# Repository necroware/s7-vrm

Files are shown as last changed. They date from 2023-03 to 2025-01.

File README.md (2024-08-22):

# Necroware's S7-VRM

This project is a Voltage Regulator Module for the Socket 7 mainboards as
defined by Intel in it's Pentium® Processor Flexible Motherboard Design
Guidelines. You can upgrade VRM capable Socket 7 mainboards with this module to
be able to use dual-voltage CPUs like Intel Pentium MMX, AMD K6, AMD K6-2 etc.

*Disclaimer: this VRM can damage your mainboard, CPU or both. Please use at your
own risk.*

__WARNING:__ *inserting the module the wrong way around would put +12V on all
critical lanes. It would destroy the mainboard, the CPU, the memory and all
expansion cards. This can't happen on mainboards with VRM socket, because there
it is not possible to insert it in reverse. On free standing VRM pin header, it
is probably a good idea to cut +12V pin 5 and the unused pin 22 to use them as
a key.*

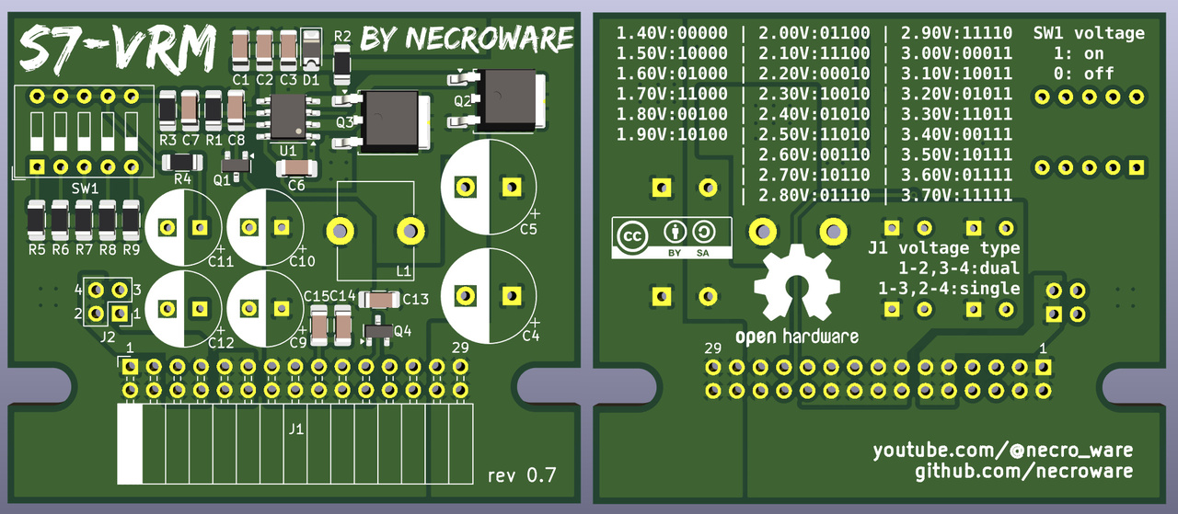
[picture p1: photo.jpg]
S7-VRM


Youtube Videos:
- Part 1: https://youtu.be/CMiGVQbMC5U
- Part 2: https://youtu.be/J0NLGfocviU
- Part 3: https://youtu.be/kBPp9EAIC8I
- Part 4: https://youtu.be/XV0b5Tvf5gY

## CPU Voltage Type Selection (J1)

There are two kind of socket 7 CPUs, single-voltage and dual-voltage CPUs.
Dual-voltage CPUs are designed to use different voltages for the internal core
and for the I/O. The I/O voltage is specified at 3.3-3.5V, but the core voltage
can be much lower. For the very power efficient AMD K6-III+EE the core voltage
is just 1.6V. 

From revision 0.6 and higher the S7-VRM supports both types of CPUs, where
for the single-voltage CPUs the voltage is completely generated on the module
and for dual-voltage CPUs the I/O voltage is generated by a linear voltage
regulator on the mainboard, where core voltage is generated on the VRM module.

To make this work you have to set the jumper J1 accordingly. Please read which
kind of CPU you have before using this module.

Voltage Type | J1 Pos.  | CPU examples
-------------|----------|---------------------------------------------------
Single       | 1-3, 2-4 | Intel Pentium, AMD K5, Winchip C6, Cyrix M1
Dual         | 1-2, 3-4 | Intel Pentium MMX, AMD K6, Cyrix M1L/MII

## CPU Voltage Selection (SW1)

__WARNING__: Single voltage CPUs are designed to run at 3.3-3.5V everything
below that value could potentially make your system unstable. Everything above
that can damage your mainboard or CPU or both. Dual-voltage CPUs usually need
core voltages far below 3.0V, AMD K6-2 for example expects only 2.2V core
voltage and everything above that can potentially damage the CPU. Always pay
attention to the CPU type you use and apply voltages out of spec only if you
really know what you are doing.

__WARNING__: different revisions can have different voltage settings, please
always pay attention and look into the proper documentation for the revision
you have.

Various voltages can be set using the SW1 switch on the module (0=off, 1=on):

Voltage | Switches | CPU Examples
--------|----------|-------------------------------------------
  1.4V  |  00000   | *Probably too low for any S7 CPU*
  1.5V  |  10000   |
  1.6V  |  01000   | AMD K6-2E+ / K6-3E+ / Mobile K6-2
  1.7V  |  11000   |
  1.8V  |  00100   |
  1.9V  |  10100   |
  2.0V  |  01100   | Cyrix MII (0,18µm version)
  2.1V  |  11100   | 
  2.2V  |  00010   | AMD Mobile K6 / K6-2(+) / K6-3(+)
  2.3V  |  10010   | 
  2.4V  |  01010   | AMD K6-2
  2.5V  |  11010   |
  2.6V  |  00110   | 
  2.7V  |  10110   |
  2.8V  |  01110   | Intel Pentium MMX, IBM 6x86L, Rise MP6 
  2.9V  |  11110   | AMD K6, IBM 6x86MX
  3.0V  |  00011   | 
  3.1V  |  10011   | 
  3.2V  |  01011   | AMD K6@233
  3.3V  |  11011   | Pentium 66-200 (Single Voltage)
  3.4V  |  00111   | 
  3.5V  |  10111   | AMD K5, Winchip C6
  3.6V  |  01111   | 
  3.7V  |  11111   | *Danger: probably to high for any S7 CPU*

## Important remarks

The transistor Q1 with integrated pull-up resistor is optional. It is used for 
enable/disable signal and is unused on most mainbards.

The PCB is made for a through hole inductor, but if you have only SMD it is also
possible to solder that instead. Keep in mind that the inductor has to stand
the required current. Also slightly different inductors are allowed, everything
between 2µH and 4,7µH should work as well. With the higher inductance you get
less current ripple, also voltage ripple can look better, but the maximum
possible current will decrease. Playing with different inductors will also
influence the compensation network.

Capacitors C7 and C8 are used in so called compensation network and are
responsible for DC-DC converter activation and stability. Those parts are very
delicate and dependent on the ESR and values of the output capacitors C9-C12,
and the inductor L1. If your regulator shows stability issues or not starting
at all, try to remove the capacitor C8. If you change any other parts C7, C8 and
R1 have to be adapted accordingly.

## Bill of materials

Part        | Count | LCSC#    | Comment
------------|-------|----------|--------------------------------------------
C1, C15     | 2     | C13585   | 10u capacitor SMD 1206              
C2, C14     | 2     | C51205   | 4.7u capacitor SMD 1206              
C3, C6, C13 | 3     | C696845  | 0.1u capacitor SMD 1206
C4, C5      | 2     | C407963  | 2200u capacitor TH Radial D10.0mm, P5.00mm
C7          | 1     | C107186  | 242n capacitor SMD 1206
C8          | 1     | C577176  | 39p capacitor SMD 1206
C9-C12      | 4     | C407858  | 1000u capacitor TH Radial D8.0mm, P3.5mm
D1          | 1     | C109000  | Switching diode
J1          | 1     | C2897435 | Connector angled 02x15 pins 2.54mm 
J2          | 1     | N/A      | 2x2 jumper
L1          | 1     | N/A      | 3.3µH inductor
Q1          | 1     | C13871   | NPN-BEC biased transistor 
Q2, Q3      | 2     | C496603  | N-MOSFET GDS at least 15A
Q4          | 1     | C454937  | PNP-BEC biased transistor 
R1, R2, R6  | 3     | C136874  | 15K resistor SMD 1206
R3, R8, R9  | 3     | C706412  | 3,75K resistor SMD 1206
R4          | 1     | C870818  | 5K resistor SMD 1206
R5          | 1     | C137314  | 30K resistor SMD 1206
R7          | 1     | C137115  | 7,5K resistor SMD 1206
SW1         | 1     | C5299506 | DIP-10 Switch THT 5 buttons 2.54mm
U1          | 1     | C382017  | ISL6545 DC-DC Controller

The inductor doesn't need to be very exact, anything between 2.5µH and 4.7µH
should work, but the sweet point is at around 3.3µH. The inductor can be self
made by using a T50 ferrite toroid. For example T50-26 with permeability 75µ
wrapped in 10 loops of 1.3 mm coper.

## Tested mainboards

This module should run with all mainboards, which provide the VRM module header
as specified in Intel Pentium Mainboard Design Guidelines. Most of such boards
were based on Intel Triton (i430FX) and VIA Apolo Master (MV series) chipsets,
but there were also quite a lot of later boards with newer chipsets (f.e.
i430VX), which supported such an external VRM as well.

Most of the mainboards which were equipped with a VRM option, were produced
before Intel Pentium MMX, AMD K6 and other dual-voltage CPUs were officially
available. However those CPUs have changed the multiplier selection behavior of
CPU pins BF0/1. Not only a new pin was introduced for higher multipliers, but
also pin BF0 was not pulled up internally anymore as it has been done on
single-voltage CPUs before. This ended up in wrong multiplier detection on newer
CPUs like Pentium MMX 200, which would be suddenly detected as 166MHz one. This
can be fixed by adding a 10k pull-up resistor to the CPU between pin BF0 I/O
VCC. In the following table of tested mainboards you can find a column R+BF0
which tells if such a pull-up resistor had to be added to properly support the
multiplier settings.

Faster Super Socket 7 CPUs, like AMD K6-2 and newer added another multiplier
selection pin BF2, which is not supported on those old mainboards at all. It
can be added using another mod, but is actually not necessary. If the CPU
multiplier is set to 2x, those newer CPUs would interpret it as 6x and for
66MHz FSB go directly to 400MHz. However to be able to detect the CPU properly
you would need to mod the BIOS. This is however optional, the system should
work also with outdated BIOS. In such a case the CPU just would not be reported
properly. 

With that in mind this VRM was tested using various CPUs and voltages on
following mainboards:

Manufacturer | Model           | Chipset | R+BF0 | BIOS Mod | VRM Compatible
-------------|-----------------|---------|-------|----------|-------------------
Asus         | P/I-P55TP4XE(G) | i430FX  | Yes   | Yes      | Yes
Gigabyte     | GA-586-ATE/P    | i430FX  | Yes   | Yes      | Yes

## License

This work is licensed under the Creative Commons Attribution-ShareAlike 4.0
International License.

## Links
* [Intel Pentium Mainboard Design Guidelines](http://netwinder.osuosl.org/pub/misc/docs/i386/24318702.pdf)

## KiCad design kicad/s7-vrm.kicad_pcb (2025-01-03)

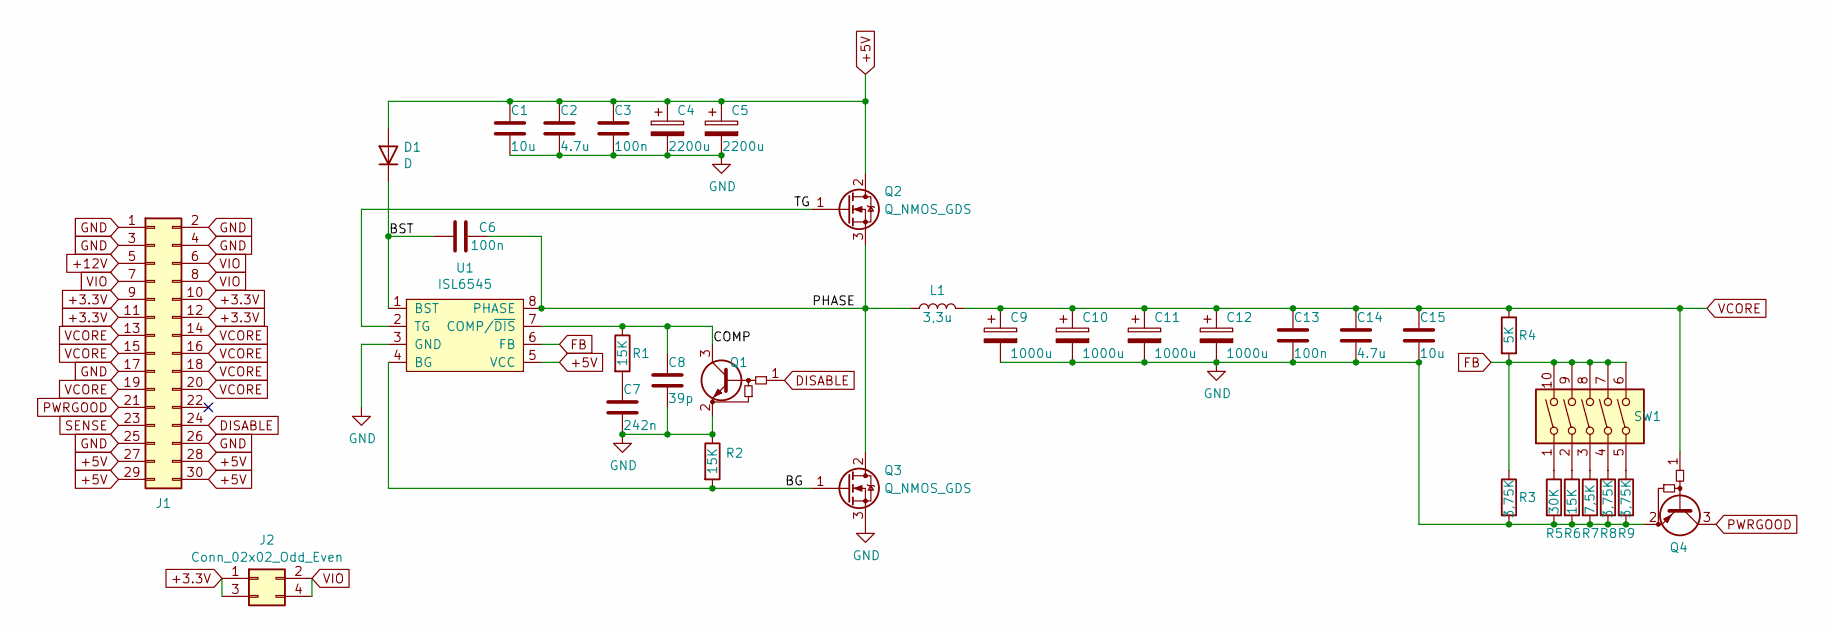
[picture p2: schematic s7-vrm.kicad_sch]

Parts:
C1, C15: 10u; C_1206_3216Metric_Pad1.33x1.80mm_HandSolder; LCSC C13585
C2, C14: 4.7u; C_1206_3216Metric_Pad1.33x1.80mm_HandSolder; LCSC C51205
C3, C6, C13: 100n; C_1206_3216Metric_Pad1.33x1.80mm_HandSolder; LCSC C696845
C4, C5: 2200u; CP_Radial_D10.0mm_P5.00mm; LCSC C407963
C7: 242n; C_1206_3216Metric_Pad1.33x1.80mm_HandSolder; LCSC C107186
C8: 39p; C_1206_3216Metric_Pad1.33x1.80mm_HandSolder; LCSC C577176
C9, C10, C11, C12: 1000u; CP_Radial_D8.0mm_P3.50mm; LCSC C407858
D1: D; D_1206_3216Metric_Pad1.42x1.75mm_HandSolder; LCSC C109000
J1: Conn_02x15_Row_Letter_First; PinSocket_2x15_P2.54mm_Horizontal; LCSC C2897435
J2: Conn_02x02_Odd_Even; PinHeader_2x02_P2.54mm_Vertical
L1: 3,3u; L_Toroid_Vertical_L16.0mm_W8.0mm_P7.62mm
Q1: Q_NPN_BEC_BRT; SOT-23; LCSC C13871
Q2, Q3: Q_NMOS_GDS; TO-252-2; LCSC C496603
Q4: Q_PNP_BEC_BRT; SOT-23; LCSC C454937
R1, R2, R6: 15K; R_1206_3216Metric_Pad1.30x1.75mm_HandSolder; LCSC C136874
R3, R8, R9: 3,75K; R_1206_3216Metric_Pad1.30x1.75mm_HandSolder; LCSC C706412
R4: 5K; R_1206_3216Metric_Pad1.30x1.75mm_HandSolder; LCSC C870818
R5: 30K; R_1206_3216Metric_Pad1.30x1.75mm_HandSolder; LCSC C137314
R7: 7,5K; R_1206_3216Metric_Pad1.30x1.75mm_HandSolder; LCSC C137115
SW1: SW_DIP_x05; SW_DIP_SPSTx05_Slide_9.78x14.88mm_W7.62mm_P2.54mm; LCSC C5299506
U1: ISL6545; SOIC-8_3.9x4.9mm_P1.27mm; LCSC C382017

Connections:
+3.3V: J1.9, J1.10, J1.11, J1.12, J2.1, J2.3
+5V: C1.1, C2.1, C3.1, C4.1, C5.1, D1.2 (A), J1.27, J1.28, J1.29, J1.30, Q2.2 (D), U1.5 (VCC)
+12V: J1.5
/BG: Q3.1 (G), R2.2, U1.4 (BG)
/BST: C6.1, D1.1 (K), U1.1 (BST)
/COMP: C8.1, Q1.3 (C), R1.1, U1.7 (COMP/~DIS)
/PHASE: C6.2, L1.1, Q2.3 (S), Q3.2 (D), U1.8 (PHASE)
/TG: Q2.1 (G), U1.2 (TG)
DISABLE: J1.24, Q1.1 (B)
FB: R3.1, R4.2, SW1.6, SW1.7, SW1.8, SW1.9, SW1.10, U1.6 (FB)
GND: C1.2, C2.2, C3.2, C4.2, C5.2, C7.2, C8.2, C9.2, C10.2, C11.2, C12.2, C13.2, C14.2, C15.2, J1.1, J1.2, J1.3, J1.4, J1.17, J1.25, J1.26, Q1.2 (E), Q3.3 (S), Q4.2 (E), R2.1, R3.2, R5.2, R6.2, R7.2, R8.2, R9.2, U1.3 (GND)
unnamed: C7.1, R1.2
unnamed: R5.1, SW1.1
unnamed: R6.1, SW1.2
unnamed: R7.1, SW1.3
unnamed: R8.1, SW1.4
unnamed: R9.1, SW1.5
PWRGOOD: J1.21, Q4.3 (C)
SENSE: J1.23
VCORE: C9.1, C10.1, C11.1, C12.1, C13.1, C14.1, C15.1, J1.13, J1.14, J1.15, J1.16, J1.18, J1.19, J1.20, L1.2, Q4.1 (B), R4.1
VIO: J1.6, J1.7, J1.8, J2.2, J2.4

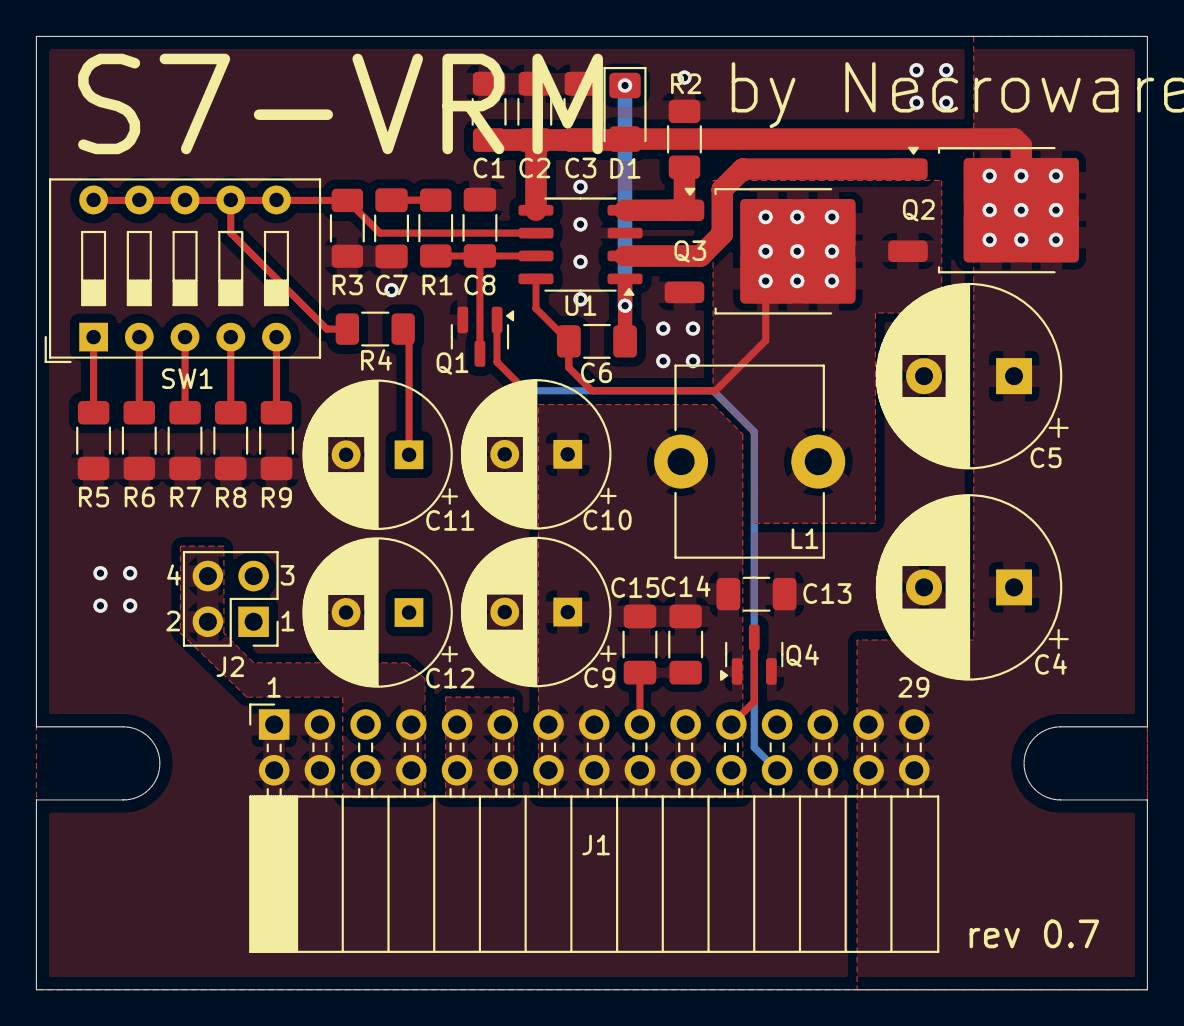
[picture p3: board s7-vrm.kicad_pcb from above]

Board: 2 copper layers, 61.7 x 53.0 mm, 34 parts (0 on the bottom side), 19 nets.

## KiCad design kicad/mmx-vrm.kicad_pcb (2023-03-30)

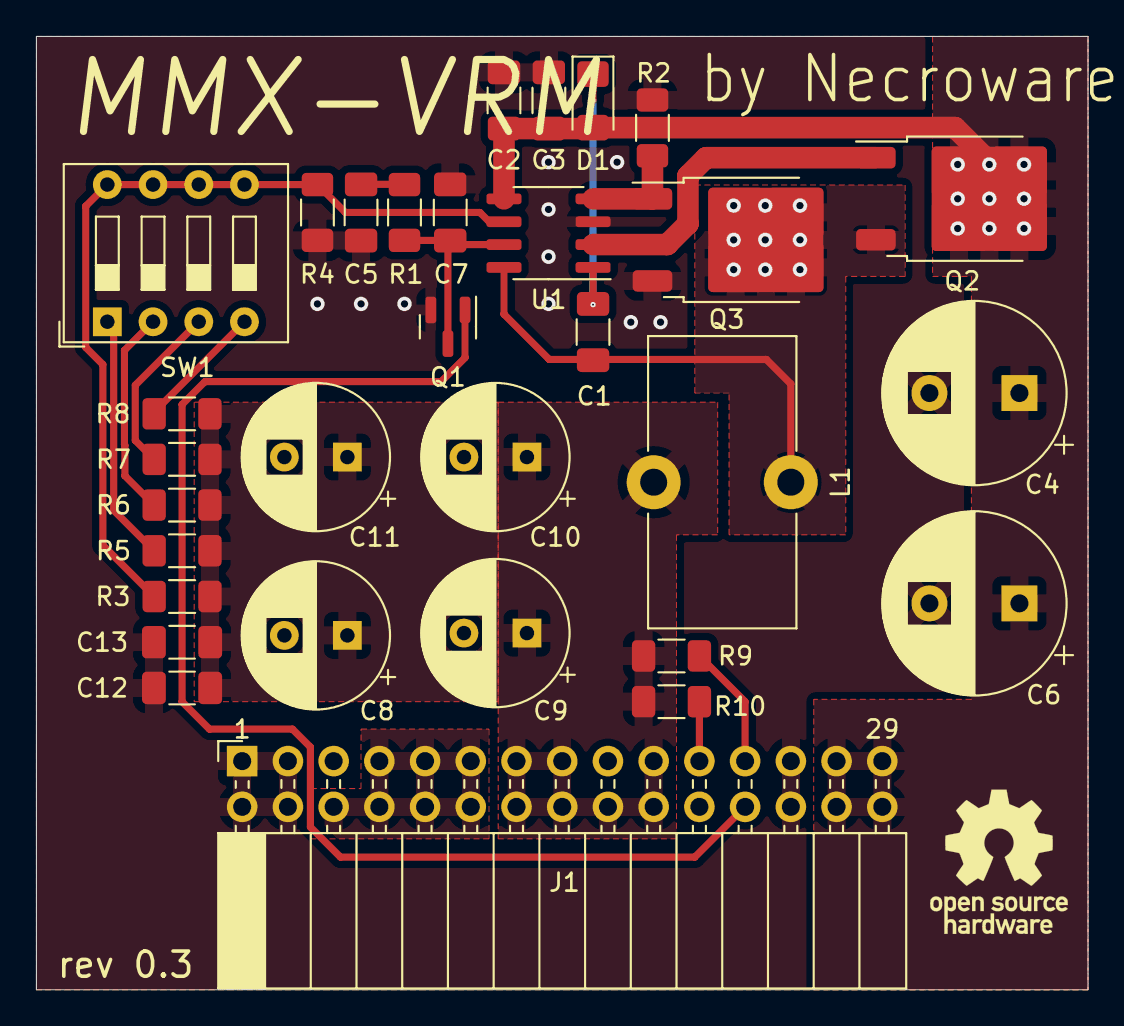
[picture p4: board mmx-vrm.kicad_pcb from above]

Board: 2 copper layers, 58.4 x 53.0 mm, 31 parts (0 on the bottom side), 18 nets.

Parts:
C1, C3, C13: 0.1u; C_1206_3216Metric_Pad1.33x1.80mm_HandSolder
C2, C12: 4.7u; C_1206_3216Metric_Pad1.33x1.80mm_HandSolder
C4, C6: 3300u; CP_Radial_D10.0mm_P5.00mm
C5: 22n; C_1206_3216Metric_Pad1.33x1.80mm_HandSolder
C7: 220p; C_1206_3216Metric_Pad1.33x1.80mm_HandSolder
C8, C9, C10, C11: 1000u; CP_Radial_D8.0mm_P3.50mm
D1: D; D_1206_3216Metric_Pad1.42x1.75mm_HandSolder
J1: Conn_02x15_Row_Letter_First; PinSocket_2x15_P2.54mm_Horizontal
L1: 2,5uH; L_Toroid_Vertical_L16.0mm_W8.0mm_P7.62mm
Q1: Q_NPN_BEC; SOT-23
Q2, Q3: Q_NMOS_GDS; TO-252-2
R1, R2, R6: 15K; R_1206_3216Metric_Pad1.30x1.75mm_HandSolder
R3, R8: 3K; R_1206_3216Metric_Pad1.30x1.75mm_HandSolder
R4, R10: 1K; R_1206_3216Metric_Pad1.30x1.75mm_HandSolder
R5: 21K; R_1206_3216Metric_Pad1.30x1.75mm_HandSolder
R7: 6,3K; R_1206_3216Metric_Pad1.30x1.75mm_HandSolder
R9: 0; R_1206_3216Metric_Pad1.30x1.75mm_HandSolder
SW1: SW_DIP_x04; SW_DIP_SPSTx04_Slide_9.78x12.34mm_W7.62mm_P2.54mm
U1: NCP1579; SOIC-8_3.9x4.9mm_P1.27mm

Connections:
+3.3V: J1.6, J1.7, J1.8, J1.9, J1.10, J1.11, J1.12
+5V: C2.1, C3.1, C4.1, C6.1, D1.2 (A), J1.27, J1.28, J1.29, J1.30, Q2.2 (D), U1.5 (VCC)
/BG: Q3.1 (G), R2.2, U1.4 (BG)
/BST: C1.1, D1.1 (K), U1.1 (BST)
/COMP: C7.1, Q1.3 (C), R1.1, U1.7 (COMP/~DIS)
/PHASE: C1.2, L1.1, Q2.3 (S), Q3.2 (D), U1.8 (PHASE)
/TG: Q2.1 (G), U1.2 (TG)
DISABLE: J1.24, Q1.1 (B)
FB: R3.2, R4.1, SW1.5, SW1.6, SW1.7, SW1.8, U1.6 (FB)
GND: C2.2, C3.2, C4.2, C5.2, C6.2, C7.2, C8.2, C9.2, C10.2, C11.2, C12.2, C13.2, J1.1, J1.2, J1.3, J1.4, J1.25, J1.26, Q1.2 (E), Q3.3 (S), R2.1, R4.2, U1.3 (GND)
unnamed: C5.1, R1.2
unnamed: R5.2, SW1.1
unnamed: R6.2, SW1.2
unnamed: R7.2, SW1.3
unnamed: R8.2, SW1.4
PWRGOOD: J1.21, R10.1
SENSE: J1.23, R9.1
VCORE: C8.1, C9.1, C10.1, C11.1, C12.1, C13.1, J1.13, J1.14, J1.15, J1.16, J1.18, J1.19, J1.20, L1.2, R3.1, R5.1, R6.1, R7.1, R8.1, R9.2, R10.2

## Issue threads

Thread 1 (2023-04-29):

Feature request: Add image of schematic

kyrreaa, 2023-04-29:
Would be great to have an image of schematic in repo as well as the board. Alternatively a pdf.
This way netizens can view it without installing Kicad. Github unfortunately does not have Kicad viewing caopabilities (yet?).
(Also: Wonderfull project! Love the youtube series!)

necroware, 2023-04-29:
I don't like duplication, because earlier or later such things get diverged and irritate more, than help. I had it already with some projects, so I removed schematics images from everywhere.

kyrreaa, 2023-04-29:
I always generate it as part of my gerber releases. That way they are archived with the docs for manufacture.

necroware, 2023-04-30:
Ok, that is a way to do it. I'll add it to the release files.

Closed 2023-04-29.

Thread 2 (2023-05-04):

two question about schematic.

youxiaojie, 2023-05-04:
two errors:
1. feed back voltage should be divided from "sense" pin
2. power good signal should be generate from a transistor.  details: serial with a resistor to baser, then emitter connected with gnd leaving float collector as power good signal.

necroware, 2023-05-04:
Second point is true, the resistor was just a shortcut, but a transistor would be a more appropriate way to solve that. The first point I don't understand, would you like to explain it a little bit more?

youxiaojie, 2023-05-08:
do you think of professional CPU powering chip meeting vrm 8.3？from 1.3 to 3.5v. I decide to do it with experimental board with adp3157.
the chips are:
CS5165/5155(H)/5157H/5159
LTC1753
IRU3004/3007/3011
HIP6004B/6004C
UCC3588/3830
LM2636/2638
TPS5210/5211
RT9223CS/9224CS/9224PS
L6911B/6911C
ADP3153/3154/3155/3157
RC5051/5052/5053/5054/5055/5057/5058
APW7004
SC1153
US3012

necroware, 2023-05-08:
I wanted to use s.t. what I can still buy new and what is easy to solder by hand.

youxiaojie, 2023-05-09:
> I wanted to use s.t. what I can still buy new and what is easy to solder by hand.

which s.t. ? the part number?

necroware, 2023-05-09:
Initially I started to look at LTC1530, which was designed for AMD K6-2 and Pentium II in mind. However, that is not obtainable anymore, so I looked for something similar, like ISL6545, NCP1587, L6726. I ended up with NCP1579, since that was deliverable at that point. Unfortunately id disappeared as well now and the next revision will probably be around ISL6545, which has slightly different reference voltage, but otherwise very similar.

Dunwood84, 2023-06-01:
Is there a file that has the board dimensions / board thickness / hole spacing /hole size on here? i'd like to make a board, but most PCB sites require board dimensions and hole sizes

necroware, 2023-06-01:
> Is there a file that has the board dimensions / board thickness / hole spacing /hole size on here? i'd like to make a board, but most PCB sites require board dimensions and hole size

Your question is not related to this topic. If you have questions please open new issue the next time, otherwise we will lose track if every question is in the same ticket. Regarding your question you probably make it wrong, just take the gerber.zip file from the releases page and upload it as is to a manufacturer of your choice. There is everything included.

gmiranda, 2023-07-11:
> Initially I started to look at LTC1530, which was designed for AMD K6-2 and Pentium II in mind. However, that is not obtainable anymore, so I looked for something similar, like ISL6545, NCP1587, L6726. I ended up with NCP1579, since that was deliverable at that point. Unfortunately it disappeared as well now and the next revision will probably be around ISL6545, which has slightly different reference voltage, but otherwise very similar.

I've assembled a board using the ISL6545 and, indeed, the voltages are different. Have you already considered what resistors values must be changed?

necroware, 2023-07-12:
@gmiranda Yes, I recalculated the values, but I'm currently not at home. I will try to update the documentation later with optional values.

necroware, 2023-07-13:
> > Initially I started to look at LTC1530, which was designed for AMD K6-2 and Pentium II in mind. However, that is not obtainable anymore, so I looked for something similar, like ISL6545, NCP1587, L6726. I ended up with NCP1579, since that was deliverable at that point. Unfortunately it disappeared as well now and the next revision will probably be around ISL6545, which has slightly different reference voltage, but otherwise very similar.
>
> I've assembled a board using the ISL6545 and, indeed, the voltages are different. Have you already considered what resistors values must be changed?

Just updated the documentation with the alternative values, which you'd need for ISL6545. Those number are only from calculation, I didn't test them yet, but they should be fine. If you test it, would be nice to have some feedback.

gmiranda, 2023-08-11:
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

Thanks, I'll be sure to leave feedback! Unfortunately, it'll take some time before the new components arrive.

gmiranda, 2023-10-23:
Hi @necroware

I've justed tested a new board assembled with an ISL6545 and the new components. Using a resistor as a load and a cheap multimeter + cheap scope (Zeeweii DSO1511g) I can see that most of the values are ok. They seem a bit low, usually by about 0.025V, which could be attributed to either my measuring equipment or the ATX PSU I'm using to power this thing up.

There's one setting that seem to be lower than the others and it's 1.7V: I get 1.627V. I'll see if it behaves the same with a real motherboard.

I'd love to verify the output ripple just as you did in your video but this scope doesn't seem to allow me in either DC or AC mode.

I'll probably skip ahead and test the VRM board with a real motherboard. I was able to boot both an MMX and a K6-2 with the old values so I'm confident it'll work as well.

Is there any particular thing you'd like me to test?

Thanks!

necroware, 2025-07-16:
Outdated. New revisions addressed this topics.

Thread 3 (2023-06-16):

Question about gerber file generation

gmiranda, 2023-06-16:
Hi, I'm new to PCB printing and this is probably a dump question.

I'm trying to generate the gerber files in order to send this to PCBWay and KiCad is telling me that "Zone fills are out-of-date. Refill?"

I don't know what this means. Is it normal or am I missing a layer?

These are the options I'm using when plotting:
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

Thanks a lot!

necroware, 2023-06-17:
You probably have changed something on the layout or may be used different version of KiCad. There is no need to generate gerber files yourself, I wouldn't even suggest it, since on the main branch there can be an untested "work in progress" state. It's better to use the gerber files from the last official release. You can find it here: https://github.com/necroware/s7-vrm/releases

Just take the [s7-vrm-0.4-gerber.zip](https://github.com/necroware/s7-vrm/releases/download/rev-0.4/s7-vrm-0.4-gerber.zip) file and drop it as is by a manufacturer of your choice.

gmiranda, 2023-06-18:
Oh, I didn't realise it was that easy. Thanks a lot!

Closed 2023-06-18.

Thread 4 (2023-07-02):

Is this inductor compatible?

gmiranda, 2023-07-02:
Hi again,

I ordered from LCSC this inductor PROD Tech PDPTAT0810-3R3M  (code C5120885), one of the few that were available. I did not, however, take into account the current specs... It is listed as having an max RMS current of 5400 and max ISAT current of 7000.

Will that be enough? I plan on running an  MMX 166 (2.8V) and a K6-2/450AFX.

The TDP of the Pentium is, according to Intel, 13.1 W. At 2.8V that would be some 4.68A. The K6, according to [Wikichip](https://en.wikichip.org/wiki/amd/k6-2/k6-2-450afx), is 18.8W, so that's 8.55W at 2.2V...

I only have basic electronic skills. Perhaps you could suggest a couple of valid part numbers in the doc?

Thanks!

necroware, 2023-07-02:
Hi, as I stated in the video and written in the documentation, I didn't find proper coil at LCSC. That's why I simply made it myself. The inductor doesn't need to be very exact, anything between 2.5µH and 4.7µH should work, but the sweet point is at around 3.3µH. The inductor can be self made by using a T50 ferrite toroid. For example T50-26 with permeability 75µ wrapped in 10 loops of 1.3 mm copper. It works also just fine with down to 8 loops and 1mm copper.

gmiranda, 2023-07-02:
Thanks for the reply. Sorry, I didn't recall that comment on the video. I did read the doc but assumed the one I found would just work... Will keep looking.

necroware, 2025-07-16:
Outdated.

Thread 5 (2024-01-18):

VRM starting problem.

Ghostdog85, 2024-01-18:
Hello, I've build vrm according your instruction. It works well, except one issue with it's starting. It happens time to time, not every boot, it can happen on cold boot or after turn off and on. I have noticed that it happen more often when voltage is set 2.0 or more. It also happen when it's set 1.8 but not so often. It seems  it doesn't happen on 1.6-1.7 volts. I tried different more powerful PSU and tried to remove C8 capacitor but it didn't change anything.

fandjelo, 2024-01-18:
Hi, with the listed parts I didn't encounter any problems, so it's going to be hard to reproduce this ob my side. Which DC-DC controller do you use? The startup sequence is highly dependent from the compensation network C7,C8,R1. It's a kind odt hard to find universal circuit for such a big range of voltages and slightly unbalanced parts can heavily affect the start of the converter. If you have problems with that, I'd also suggest to remove Q1 for experiments. It is used for shutting down, but most mainboards don't use this signal anyway and it can affect the compensation network.

necroware, 2024-01-18:
Hi, with the listed parts I didn't encounter any problems, so it's going to be hard to reproduce this ob my side. Which DC-DC controller do you use? The startup sequence is highly dependent from the compensation network C7,C8,R1. It's a kind odt hard to find universal circuit for such a big range of voltages and slightly unbalanced parts can heavily affect the start of the converter. If you have problems with that, I'd also suggest to remove Q1 for experiments. It is used for shutting down, but most mainboards don't use this signal anyway and it can affect the compensation network.

Ghostdog85, 2024-01-18:
I used NCP1579. I'll try to desolder Q1 and test. Also I used 15,2K R1 resistor instead of 15K. Could it affect the starting of vrm ?

Ghostdog85, 2024-01-20:
Hi, it seems like removing Q1 fixed the issue. Now it turning on every time.  As Q1 I also used DTC143ECA.

necroware, 2024-01-21:
Ok, thank you for your feedback. Then we have to find an alternative part for the Q1, something with much higher internal resistance.

Ghostdog85, 2024-01-28:
I'm not sure that I understand what the disable signal is for.  Is it part of MMX self protection technology ? I'm using this VRM with K6-3+ CPU. Maybe it is not nessasery for AMD processors ?

necroware, 2024-01-28:
It's not neccessary indeed. I just followed the specs in the implementation. Some mainboards have a jumper to switch between different VRM modules and they can be deactivated using that signal. Probably also for delayed startup this can be used, but so far, I didn't see any mainboards, which would really need this. If it doesn't work in your case, just remove it. Please don't forget, though this VRM works, it is still not perfect and needs more testing and improvements in the future. May be we can avoid disable function completely.

necroware, 2025-07-16:
The stability on newer revisions was improved, so this ticket is mostly outdated.

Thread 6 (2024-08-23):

Confirmed working: IBM Aptiva

Geoman, 2024-08-23:
IBM Aptiva 2168-931
Mainboard OEM: Universal Scientific Industrial Co., Ltd
Chipset: Opti 82C557M Viper-N+
BIOS: BGOGR1L 12/29/98
CPU: AMD-K6-III+, 400 Mhz, 66 MHz Bus Clock, Multiplier 6x
Socket 7
4x32MB Kingston EDO RAM 60ns
s7-vrm revision 0.4 running flawlessly
prior I had a Kingston PowerChip-Socket for split-voltage in use, that ran extremely hot, sometimes the PC did not start

Geoman, 2024-08-23:
K6-III+/400ATZ, no modding necessary

necroware, 2024-08-23:
Wow! Very cool! An Opti board this is a great news, that it works there as well. Thank you very much. I will add it to the list of tested boards then. Is it this one? https://theretroweb.com/motherboards/s/universal-scient-pro-57a

Geoman, 2024-08-29:
> Wow! Very cool! An Opti board this is a great news, that it works there as well. Thank you very much. I will add it to the list of tested boards then. Is it this one? https://theretroweb.com/motherboards/s/universal-scient-pro-57a

Yes, this is it exactly!

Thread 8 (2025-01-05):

Revision 0.7 sense pin

Gouster4, 2025-01-05:
Using sense pin was awesome idea, and voltage can be more precise.
I understand that it can lead into issues on some boards, thats why version 0.7 came out.
Thats why i thougt that instead of completly giving up on sense pin, it would be ideal to be able to switch between using sense pin or using regulator output for sensing.

First i thought about adding one more row to dip swtich, but those are just two pin switeches that connect or disconnects two contacts from each other. In our case we would need 3 pin switch to switch sense between regulator output or sense pin. Easiest way would be 3 pins and jumper. But we dont need carry lot of current here, and added potential resistance of oxidated contacts (they can oxidate over time, specially when scraped while pluggin in and out).

So, solution that i thought about at end was small 3pin switch that can be seen on many laptops as switch that turns on/off wlan.
I attached images of some possibilities for switch that came to my mind.
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

necroware, 2025-01-05:
I thought about that, but the sense pin is there to compensate the connector resistance and losses on the mainboard. That resistance is quite low, so the sense pin would compensate just a little bit. Adding another switch or jumper would introduce additional resistance, which would push the error in the other direction. So, without the sense pin at all, we would get slightly lower resistance. With a switch/jumper we would potentially get slightly higher voltage, dependent on the quality and purity of the switch/jumper. I also thought about doing a zero voltage resistor, or solder jumper, but then it requires soldering skills to switch. So, eventually I decided to drop it completely. As I described in the release, it's more important to maintain compatibility with as many boards as possible, than to have a super exact voltage. Ignoring sense pin would still give us a very good voltage approximation.

Gouster4, 2025-01-05:
> I thought about that, but the sense pin is there to compensate the connector resistance and losses on the mainboard. That resistance is quite low, so the sense pin would compensate just a little bit. Adding another switch or jumper would introduce additional resistance, which would push the error in the other direction. So, without the sense pin at all, we would get slightly lower resistance. With a switch/jumper we would potentially get slightly higher voltage, dependent on the quality and purity of the switch/jumper. I also thought about doing a zero voltage resistor, or solder jumper, but then it requires soldering skills to switch. So, eventually I decided to drop it completely. As I described in the release, it's more important to maintain compatibility with as many boards as possible, than to have a super exact voltage. Ignoring sense pin would still give us a very good voltage approximation.

I understand. So, switch or any aditional mechanical part provides worse sensing than one used from regulator output.

Then i guess, solder jumper can be the way, while between solder jumper pads can be thin via connecting regulator sensing to regulator output as rev7 was meaned, but it would be possible to easely scrape that via and solder bridge between sense pin pad and regulator sensing pad in case someone would want to use it.

So basically solder jumper would be bridged by default to wider support instead of using sense pin, but via this tiny via between pads instead of solder blob.

Also, average between voltage on regulator output and one that comes from sense pin is about precise voltage on cpu. because both vias on motherboard are leading from same vrm to same cpu, just different pin numbers. that makes it like two almost identical resistors, and voltage between two same resistors is exactly (V1+V2)/2, so mathematical average between those two.
But i dont know if such a averaging voltage can be even implemented to voltage sensing of regulator. It was just my thought how i think it works, but i dont have any clue of implementing it. Maybe even if it would be possible, it would be too much effort with miserable benefit.

necroware, 2025-01-05:
That's all is as always a question of effort. A soldered wire from the sense pin to vcore is also an option. A real jumper or switch is definitely not great, because it will add additional resistance as I explained. I think for now it's not terrible to ignore the sense pin completely, but may be in the future revisions I will add something. Let's see what kind of good ideas the future brings.

Gouster4, 2025-01-06:
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
I imagined something like this.
Via is on PCB that does connect vrm sensing to vrm output.
But red drawing shows how via can be cut, and other two pins bridges to get sense pin working again in case that user would be sure that his board does support it.

Closed 2025-01-06.

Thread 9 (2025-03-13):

Planning on installing on IBM PC 330

priangle, 2025-03-13:
Hey Necroware! Happy to see such a project. My machine is [IBM PC 330 (Model 6577)](https://theretroweb.com/motherboards/s/ibm-pc-330-350-series-type-6577,-6587) and i am planning on making your VRM module for it. I am a bit worried for the compatibility though, because the machine is OEM, and who know what proprietary modifications to the vrm module IBM has made.
I found the [schematics for the original VRM module for this exact machine](https://www.digchip.com/datasheets/download_datasheet.php?id=675559&part-number=MP55C-3.3-2.8) and the pinout scheme seems to be identical to that you showed in your [first youtube video](https://www.youtube.com/watch?v=CMiGVQbMC5U) (9:30).

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
this is how the motherboard socket look right now

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
i've got myself a cheap donor motherboard (to the right) to solder out the proper VRM socket, gonna begin the process by soldering it to the IBM board. Only there's some resistors in the way, in the VRM socket area, they are about a half a mm in height, and they prevent the socket to lay flat on the board and the pins to puncture it properly. Not sure what to do about them, except drilling the corresponding areas of the socket on the router for it to have the space for those resistors :/

necroware, 2025-03-13:
Looks interesting. Meanwhile I tested some boards with my adapter and it turned out that not all of those follow the specs. You have to check couple of things.

I see, that you already have the latest rev 0.7, which works around an issue with the SENSE pin which is not connected to VCORE on some boards. So if your board has such an issue, that wouldn't be a problem with this revision of the module.

Following steps you will have to do without (!) a CPU installed.

You will have to remove resistors R46, R47, R52, R53. Those are the same as the jumper wires which I removed in my first video. Those 0 Ohm resistors short 3.3V I/O voltage to VCORE. You don't want this, since S7-VRM shall control the voltage.

Regarding R27, R38, R15, R18 you will have to find out what those resistors are  connecting using a multimeter in continuity mode. I assume those resistors should be also removed in case a VRM module is used, but you will have to analyze those resistors aim. Try to make a schema and send a picture here.

After you are done with resistors, before you install the VRM header check out that the I/O voltage pins are NOT connected to VCORE. Unfortunately I found one board where those pins were permanently connected. The board had no I/O and VCORE plane split and despite having a VRM header it was not possible to install any. That was definitely a hardware design bug which I hope your board doesn't have.

Don't hesitate to answer your questions here, I'd be glad to add to the documentation if this board is compatible or not.

priangle, 2025-03-13:
Thanks you so much for a quick and thorough reply! Going to do everything you mentioned. Regarding the resistors, maybe that explains why they obstruct the proper placement of a plastic vrm header - because they need to be removed when using the vrm module.

forgot to mention that the datasheet for the vrm module has been found on [this vogons thread](https://www.vogons.org/viewtopic.php?t=81718), where OP has the same system as me.

priangle, 2025-03-13:
another hint i found is that the official IBM module (P/N 76H3658) is called ["IBM Aptiva Voltage Regulator"](https://www.memory4less.com/ibm-cpu-vrm-and-accessory-76h3658) on memory4less.com, which is interesting (if it's not a naming error) because another user here already confirmed that your module [works on Aptiva](https://github.com/necroware/s7-vrm/issues/6)

necroware, 2025-03-13:
Ok, that looks promising.

priangle, 2025-03-14:
in order to analyze resistors R38, R27, R18, R15 i've removed them first, then checked both of their solder points separately for all 30 vrm pins

this is how it looks right now:
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

so using a multimeter i've made this map, in which:
green connection means no resistance between two points
yellow connection means varied resistance (value changes when swapping red and black needles of multimeter)
red connection means no connection in one direction, and a lot of resistance the other way
no connection means no connection
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

as you can see, R38 and R27 are identical, as well as R18 and R15

hope the scheme is readable! :)

necroware, 2025-03-14:
Wow, that is a very nicely made scheme. R18 and R15 look to be the same as R46, R47, R52, R53 - those resistors are there to bridge 3.3V onto VCORE. Unfortunately looking at this it doesn't look good since on all of your schemas you seem always to have I/O connected with VCORE. It could be that this board has the same issue as what I mentioned above. Looks like the I/O plane is not separated from the VCORE plane. If you remove all resistors, you should not have connection between the VRM pins A4, B3, B4 and A7, A8, A10, B7, B8, B9, B10.

If those pins are connected, than you can't control I/O and VCORE voltage separately. Are the more 0 Ohm resistor around which are connected to the named pins?

priangle, 2025-03-14:
here are the closest 0Ohm resistors
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

necroware, 2025-03-14:
I saw those, they are actually too small, for power transmission. On the other hand I/O voltage doesn't need too much. Are some of those resistors connected to the I/O voltage pins?

priangle, 2025-03-14:
> If you remove all resistors, you should not have connection between the VRM pins A4, B3, B4 and A7, A8, A10, B7, B8, B9, B10.

i've checked this little guy and it is connected to A4, B3, B4, A7, A8, A10, B7, B8, B9, B10!
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

necroware, 2025-03-14:
Only that one? :) That's really unexpectedly small. But ok, if you remove it, will you still have connection between A4, B3, B4 and A7, A8, A10, B7, B8, B9, B10?

priangle, 2025-03-14:
i was too afraid to check the rest of them but now i see that they all lead to these pins :D the rabbit hole gets bigger and bigger

priangle, 2025-03-15:
> if you remove it, will you still have connection between A4, B3, B4 and A7, A8, A10, B7, B8, B9, B10?

nah, out of curiosity i removed this one res, and it didn't had any effect.

another interesting finding is that after removing R38 and R27 there is still connection between their solder points

priangle, 2025-03-15:
look what i found on ebay - [mmx version of this board](https://www.ebay.com/itm/186911082217?_skw=ibm+socket+7+motherboard+mmx)

i think i will contact the seller and ask him to make a detailed top-down photo of VM area :))
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

priangle, 2025-03-15:
found another one, asked the same )
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

necroware, 2025-03-15:
> nah, out of curiosity i removed this one res, and it didn't had any effect.

If only one of those is left you will still have continuity through that, so either all or none :)

> another interesting finding is that after removing R38 and R27 there is still connection between their solder points

That is basically what I previously wrote. I'm also confused that it makes no difference if those resistors are installed or not. I think there are more of those and these resistors are there to distribute the current flow.

priangle, 2025-03-15:
another interesting finding
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

priangle, 2025-03-15:
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
priangle, 2025-03-15:
so you think it's worth trying to remove them and see what happens? :)

necroware, 2025-03-15:
I mean you already got so far :)

priangle, 2025-03-15:
Wow. I removed all these Rs and now there's no connection between I/O and VCORE. Seems that it helped!
only between A4 and A7 there seems to be some Cap on the way (starts with some resistance, gets to "1" in about 2 secs (1 means no connection)), all other connections are no more!

Anyway it seems i need two detailed photos from the board with VRM socket - one of the VRM area, other from the CPU area.

Maybe i should offer some money to the sellers for these photos :D

necroware, 2025-03-15:
Nice! I think all you would see from the pictures are the capacitors, which we already can see a little bit on the pictures which you've found. So I would just move on. Those caps which should be there instead of the resistors are optional and once you install the VRM you can measure the output voltage before you insert the CPU. The I/O voltage is not affected by the VRM module, it just wires it through or not, dependent how you set the jumpers. And the VCORE can be measured with a multimeter.

I guess it's time to build the VRM module ;)

priangle, 2025-03-16:
I have a few weeks before i receive my LCSC order, so in the meantime i might as well try to take a look at the mmx version of the board to make sure that everything's perfect:) not sure i can visually identify the parameters of needed caps though, but i think they're all identical around the board...

btw, one of the sellers actually replied, and told he will ask his tech guy to make the photos i requested!

priangle, 2025-03-28:
Hey there! Huge update on my case!
since our last conversation i contacted 5 sellers, and none of them ended up sending the detailed photos of desired spots of the board. Yesterday i continued the search and tried every possible query and eventually stumbled upon the same board as mine equipped with VRM header - what's interesting, the board have a different part number and presented by the seller as salvaged from a completely different IBM machine. As a last straw of hope, i contacted him and voila! He answered almost instantaneously and today i received the cherished photos.

Here are the side by side photos:

CPU socket area
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

VRM socket area
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

priangle, 2025-04-22:
Hey! The components arrived and i plan to build the module in a day or two. i was wondering, what's the safest way the check the module without damaging the CPU? You've mentioned that i can check the voltage without the CPU installed, can you elaborate please?

Thanks in advance!

necroware, 2025-04-24:
Hi, sorry for the late answer. Great to see this getting there! To test this you can connect an external power supply to the +5V / GND pins on the VRM module and check if the VCORE output voltage corresponds to the setup on the switches. Just like I showed it in one of the videos about this VRM.

priangle, 2025-04-24:
Hey! Thanks for the reply! The module is finished, gonna try to test it and hopefully boot the pc later today!

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

necroware, 2025-04-24:
Nice! The coil looks a bit underrated, if the voltage gets unstable, or the coil too hot, try to get something beefier.

priangle, 2025-04-24:
> Nice! The coil looks a bit underrated, if the voltage gets unstable, or the coil too hot, try to get something beefier.

https://www.lcsc.com/product-detail/Power-Inductors_BOURNS-RLB0914-3R3ML_C1329807.html
this is the coil i've been recommended for this build, i'll look into how it performs as you suggested

priangle, 2025-04-25:
i tried to check the voltage of VCOREs without the CPU but i cant interpret the results. i connected the black needle to one of the Vss pins and the red one to VCOREs. here's the results:
PIN A7 - 5.045 v
PINS A8 B8 B9 - 2.246 v
PINS A10 B10 - 1.505 v
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

necroware, 2025-04-25:
I think you count the PINs from the wrong side. A1-2, B1-2 is ground, A14-15, B14-15 is +5V. You seem to count in reverse and if so, then the 2.246V you get should be VCORE. If you set 2.2V on the switches, then it looks right. The other voltages are strange, that should be 3.3V and ground if I count it right. Check out the pinout once again:

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

necroware, 2025-04-25:
3.3V for I/O comes from the mainboard and is not controlled by the S7-VRM. That voltage is specified to be between 3.3V and 3.5V so it should be fine.

priangle, 2025-04-26:
fully assembled the machine and everything seems to be in order. I think that means that the project is a success! as a precaution i just need to check the temp on the coil..
Thank you so much for your help and for this project project! I've renamed the issue

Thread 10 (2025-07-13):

Intel Thor is not supported, voltage stuck at the same level.

aderius, 2025-07-13:
Hello,

I put together the 0.6 version for the [Intel Advanced/ATX (Thor )](https://theretroweb.com/manufacturers/207). I changed the pin at J10K1 on the motherboard per the [manual](https://theretroweb.com/motherboard/manual/advanced-atx-4615-5f07978170bdd200457643.pdf) (and tried both settings for good measure). Regardless of how I configure the VRM, there is no change in Vcore voltage with or without it connected. I reassembled the VRM again on a new board just to be sure everything was soldered properly. I was wondering if you had any ideas regarding next steps.

necroware, 2025-07-13:
I have Thor on my TODO list. As far as I know it seems not be supported out of the box. It's not enough to solder the VRM header, also the board has to be modified as far as I saw. From the factory the I/O and Core voltage planes are not separated there and I don't know if it possible there. In the worst case Intel didn't follow its own specification on that board.

I have my a Thor at hand, but the mainboard is dead and needs to be repaired first. I take a look this week.

aderius, 2025-07-13:
Thank you very much for your reply! One thing I did try is removing the 0 ohm resistors on the board that connect to the vcore pins 22-25 (one of the IO pins has one as well) but that made no difference. Looking forward to what you find.

necroware, 2025-07-13:
You are lucky, I had some time today and this board was on my TODO list far too long. I repaired it and modified for the S7-VRM. You have to remove following 0 Ohm resistors, which connect I/O and Vcore planes from factory. If you don't remove all of those resistors, the on-board 3.3V/3.5V regulator will override the external VRM.

The 0 Ohm resistors to remove (sorry, the silk layer is somewhat hard to read, but I hope I got the names right):
- R2M5
- R3M4
- R3M2
- R3M5
- R3M6
- R4K3
- R5L1

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

aderius, 2025-07-14:
You are a legend - thank you very much!

aderius, 2025-07-16:
Belay that - when I insert a CPU, there seems to still be a connection between VIO and VCORE, thus circumventing the VRM. Without the CPU inserted, it's no problem. Looks like I have more investigating to do...

Closed 2025-07-27.

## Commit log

2021-08-22 Resistors annotation renumber
    [mmx-vrm.kicad_pcb, mmx-vrm.sch]
2021-08-23 Thermal improvements
    [mmx-vrm.kicad_pcb]
2021-08-23 Minor layout improvements
    [mmx-vrm.kicad_pcb]
2021-09-06 Improve clearance, rev 0.3 started
    [mmx-vrm.kicad_pcb, mmx-vrm.sch]
2021-10-23 LCSC number for the voltage regulator
    [mmx-vrm.sch]
2021-11-19 Fixes after first tests
    [mmx-vrm.kicad_pcb, mmx-vrm.sch]
2021-11-19 Readjusted the resistors for 3.2V support
    [mmx-vrm.kicad_pcb, mmx-vrm.sch]
2021-11-19 Renamed project into s7-vrm
    [s7-vrm.kicad_pcb, s7-vrm.sch]
2021-11-20 Tweaked lower voltages
    [s7-vrm.sch]
2021-11-20 Added docs
    [vrm_params.ods]
2021-11-20 Revert "Renamed project into s7-vrm"
    This reverts commit abb7c84a7e06dd52f3d76b1c246c1366ac80b644.
    [mmx-vrm.kicad_pcb, mmx-vrm.sch]
2021-12-02 First raw version
    [mmx-vrm.kicad_pcb, mmx-vrm.sch, vrm_params.ods]
2021-12-02 Improved power lines
    [mmx-vrm.kicad_pcb]
2021-12-14 Add LCSC IDs and documentation
    [mmx-vrm.kicad_pcb, mmx-vrm.sch, vrm_params.ods]
2022-01-04 Minor fixes.
    - Changed LCSC part numbers (due to shortage)
    - Enlarged GND plane distance
    [mmx-vrm.kicad_pcb, mmx-vrm.sch]
2023-02-26 Switched to KiCad 7
    [mmx-vrm.kicad_pcb, mmx-vrm.kicad_sch, mmx-vrm.sch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]
2023-03-27 Wide version
    [mmx-vrm.kicad_pcb, mmx-vrm.kicad_sch, vrm_params.ods]
2023-03-30 Updated parameters
    [mmx-vrm.kicad_pcb, mmx-vrm.kicad_sch, vrm_params.ods]
2023-04-01 Renamed project
    [s7-vrm.kicad_pcb, s7-vrm.kicad_sch]
2023-04-01 Revision 0.4
    - Added optional 1uF capacitors on input and output
    - Increased the size of the inductor pins for SMD option
    - Minor layout fixes
    - Updated silk layer, logos etc.
    [s7-vrm.kicad_pcb, s7-vrm.kicad_sch, vrm_params.ods]
2023-04-01 Updated documentation and part numbers
    [s7-vrm.kicad_sch, vrm_params.ods]
2023-04-01 Updated logos, readme and photo
    [s7-vrm.kicad_pcb]
2023-04-03 Calculations fixes
    [vrm_params.ods]
2023-04-03 Layout improvements
    [s7-vrm.kicad_pcb, s7-vrm.kicad_sch]
2023-04-03 Fixed BOM in readme, fixed part numbers in schematics
    [s7-vrm.kicad_pcb, s7-vrm.kicad_sch]
2023-04-03 Update parts numbers
    [s7-vrm.kicad_sch, vrm_params.ods]
2023-04-09 Layout improvements, added slits for the clips
    [s7-vrm.kicad_pcb, s7-vrm.kicad_sch]
2023-04-12 Fixed resistor labels in the calculations
    [vrm_params.ods]
2023-04-22 Updated parts and documenttion
    [s7-vrm.kicad_pcb, s7-vrm.kicad_sch, vrm_params.ods]
2023-04-22 Set suggested coild wire to 1.3mm
2023-04-22 Prepared rev 0.5
    - Increased voltage range now 1.6-3.5V
    - Moved FB resistors to lower part
    - Reduced the height slightly
    - Improved location of filter caps
    - Unified some resistors values
    [s7-vrm.kicad_pcb, s7-vrm.kicad_sch]
2023-04-22 Updated parts, fixed project after broken merge
    [s7-vrm.kicad_pcb, s7-vrm.kicad_sch, vrm_params.ods]
2023-04-23 Increase PCB width slightly
    [s7-vrm.kicad_pcb]
2023-04-28 Take shorter input capacitor
    [s7-vrm.kicad_pcb, s7-vrm.kicad_sch]
2023-04-30 Update R calculations
    [vrm_params.ods]
2023-05-08 Using sence to FB and transistor for PWRGOOD
    [s7-vrm.kicad_pcb, s7-vrm.kicad_sch]
2023-07-12 Work in progress
    [s7-vrm.kicad_pcb, s7-vrm.kicad_sch, vrm_params.ods]
2023-07-13 Added alternative resistor values for ISL6545
2023-12-29 Prepared for production
    [s7-vrm.kicad_pcb, s7-vrm.kicad_sch, vrm_params.ods]
2024-01-09 Update LCSC parts and values
    [s7-vrm.kicad_pcb, s7-vrm.kicad_sch]
2024-06-06 Swap R3 and R4 to get proper voltage
    [s7-vrm.kicad_pcb, s7-vrm.kicad_sch, vrm_params.ods]
2024-06-23 prepare rev 0.6
    [s7-vrm.kicad_pcb, s7-vrm.kicad_sch, vrm_params.ods]
2024-06-23 updated readme and bom
    [s7-vrm.kicad_sch, vrm_params.ods]
2024-06-25 minor layout fixes
    [s7-vrm.kicad_pcb]
2024-06-25 silk layer fixes
    [s7-vrm.kicad_pcb]
2024-06-25 changed edge infill
    [s7-vrm.kicad_pcb]
2024-06-25 add gerber subfolder to export settings
2025-01-03 Drop sense pin usage.
    Some mainboards don't implement sense pin properly and have other
    signals connected to that pin. This can lead to invalid output voltage
    reading. In the worst case sense could be bound to ground, which would
    report 0V to the controller all the time, which would try to ramp up
    the voltage to the maximum of about 4.4V. This could potentially kill
    the CPU, especially low voltage K6-II or similar.
    Due to this issue, the feedback voltage is now read directly at the
    vcore output. This could potentially lead to slightly lower output
    voltage at the CPU, since we would not read the sense from there, but
    it is much safer and would work on more mainboards.
    [s7-vrm.kicad_pcb, s7-vrm.kicad_sch]
